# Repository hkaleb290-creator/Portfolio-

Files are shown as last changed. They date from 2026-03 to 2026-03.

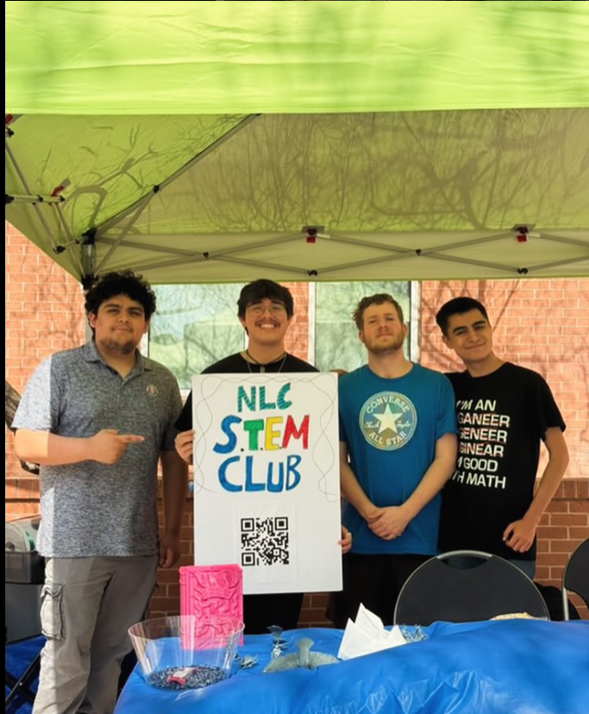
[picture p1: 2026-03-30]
1500.png

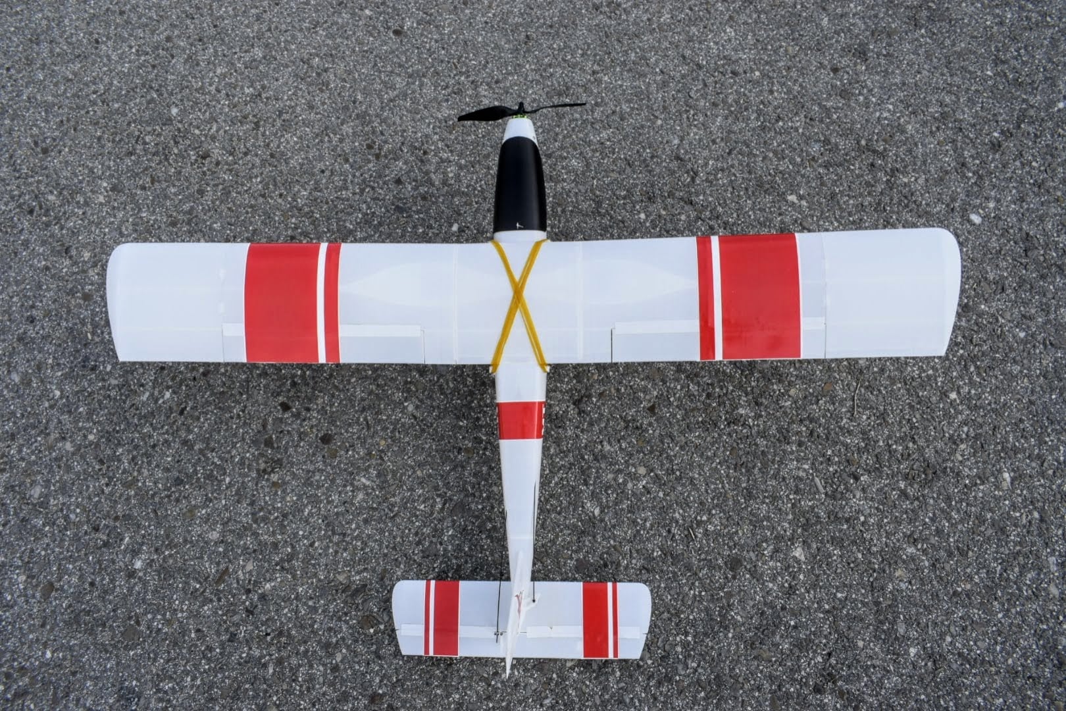
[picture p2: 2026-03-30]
images/_DSC0056.jpg

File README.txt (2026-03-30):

Free RC airplane by Eclipson on Thingiverse: https://www.thingiverse.com/thing:3302937

Summary:
-Free version of the 3D printed RC airplane Eclipson Model T. The free version available here does not include landing gear and floats. You will need to hand launch the airplane. Installing a folding propeller is recommended to avoid breaking it during landing.-More information about Eclipson: https://www.eclipson-airplanes.com/https://www.youtube.com/watch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

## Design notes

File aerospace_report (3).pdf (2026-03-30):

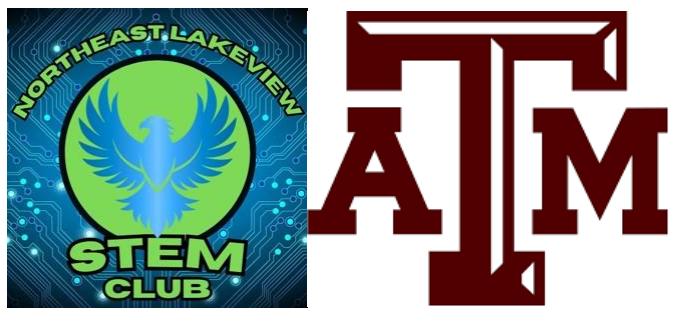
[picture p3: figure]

NLC STEM Club | Environmental Monitoring UAV | Page 1 of 23

### NLC STEM Club

Northeast Lakeview College (Alamo Colleges)

# Fixed-Wing UAV Design and Environmental Data Acquisition Using Additive Manufacturing

Lead Researchers
Aiden Ware Bosanko · Kaleb Harris · Jorge Cruz William Van Cleave · Isaiah Jimenez · Angelo Mejia

Faculty Advisors
Prof. Mitchell · Prof. Dan Ball · Prof. Sue Stankus · Prof. Rebecca Guevara

Northeast Lakeview College (Alamo Colleges) September 11, 2025 — March 2026

### Table of Contents

### 3. Results and Data Analysis | TBD

## Fixed-Wing UAV Design and Environmental Data Acquisition Using Additive Manufacturing

Author(s)/Researchers:
- Lead Researchers/Principal Investigators: Aiden Ware Bosanko (Mechanical), Kaleb Harris (Mechanical & Software), Jorge Cruz (Mechanical, Software & Research Lead), William Van Cleave (Mechanical), Isaiah Jimenez (Electrical), Angelo Mejia (Electrical)
- Researcher Contributors/Collaborators: Samuel Cedeno, Kyle McCracken, Alex (Electrical), Austin (Electrical), Tyler Rankins (Electrical)
- Support/Technical Contributors: Navora Medina (Historian), Talan (Software), Chris (Software)
- Faculty Advisors: Professor Mitchell, Professor Dan Ball, Professor Sue Stankus, Professor Rebecca Guevara

Institution: Northeast Lakeview College (Alamo Colleges)
Date: September 11, 2025

Abstract

Introduction: Air quality in the San Antonio region is a documented public health concern, yet spatially distributed, low-altitude atmospheric data remains scarce. The NLC STEM Club at Northeast Lakeview College set out to change that by designing, building, and flying a 3D-printed fixed-wing UAV capable of collecting real-time air quality and atmospheric data across the greater San Antonio area.
Methodology: We selected the open-source Eclipson Model T airframe and fabricated it using Lightweight PLA (LW-PLA) filament, reinforced with carbon fiber wing spars. A Matek F405-WMN flight controller running INAV firmware handles all autonomous and manual flight operations. We mounted a separate Arduino Nano microcontroller to manage the sensor payload — a BMP280 atmospheric pressure sensor and an MQ135 air quality sensor — logging all readings to a SanDisk 32GB microSD card every two seconds.
Results: Physical assembly of the integrated system began March 22, 2026, following 28 weeks of design, procurement, and fabrication work. Flight testing and sensor data collection are scheduled to follow. Results — including GPS-logged flight tracks, air quality readings, and pressure-altitude profiles — will be documented and added to this report upon completion.
Conclusion: We show that a college STEM club can design, build, and fly a capable research-grade UAV using accessible components and open-source tools for under $500. Our dual-subsystem architecture — separating flight avionics from the sensor payload — is practical, reproducible, and extensible for future environmental research programs.

### 1. Introduction

### 1.1. The Growing Role of UAVs in Environmental Science

UAVs have become one of the most powerful tools available for environmental monitoring. They can reach remote or hazardous locations, fly at low altitudes, and carry modular sensor payloads — all at a fraction of the cost of manned aircraft. Traditional ground-based monitoring stations do important work, but they're stuck in one place. UAVs break that limitation by enabling dynamic, geographically distributed sampling missions that teams can deploy and reconfigure quickly.

The urgency of this research is underscored by local conditions. According to the American Lung Association's 2025 State of the Air report, the San Antonio–New Braunfels–Kerrville metro area ranked 20th worst in the nation for ground-level ozone pollution, with Bexar County averaging 10.7 unhealthy ozone days per year — earning a failing grade. Contributing factors include vehicle emissions, proximity to the Eagle Ford Shale oil and gas development, industrial activity, and the region's valley geography, which traps pollutants during temperature inversions. Fixed-wing UAVs offer a uniquely powerful tool for studying these conditions, enabling spatially distributed, low-altitude sampling across the neighborhoods, corridors, and open areas that fixed ground stations cannot reach.

The NLC STEM Club built this UAV to collect real-time environmental data — air quality, atmospheric pressure, temperature, and humidity — over the San Antonio area. We deliberately chose a fixed-wing platform over a multirotor because fixed-wing aircraft are more aerodynamically efficient and cover more ground on the same battery. Using the Eclipson Model T as our base airframe and building a custom electronics and sensor stack on top of it, our goal was a capable, reproducible, well-documented research platform that other student teams could replicate.

### 1.2. From Quadcopter to Fixed-Wing: A Platform Evolution

We originally planned to build a quadcopter. After a series of team discussions and a hard look at our mission requirements, we switched to fixed-wing. Quadcopters are easy to build and can hover, but they burn through battery life fast just staying in the air. For a mission focused on covering ground and sampling air quality across a wide area, that's a serious limitation. Fixed-wing aircraft glide efficiently and stay airborne much longer on the same power. The switch meant more work for our Mechanical team, who had to redesign and reprint the entire airframe — but the performance gains are worth it.

### 1.3. Research Objectives and Scope

The primary objectives of this project are:

- To design, fabricate, and assemble a fully functional 3D-printed fixed-wing UAV using the Eclipson Model T airframe as the structural foundation.
- To integrate a complete electronics stack including a flight controller, GPS module, ESC, brushless motor, servos, and an RC link capable of autonomous and manual flight.
- To develop and deploy an onboard environmental sensor payload — including atmospheric pressure and air quality sensors — managed by an Arduino Nano microcontroller.
- To log all collected environmental data to onboard storage for post-flight analysis and reporting.
- To document the full design, build, integration, and testing process in a formal research report suitable for academic and portfolio use.

### 1.4. System Overview

At a high level, the UAV system operates as two independent but physically integrated subsystems. The first is the flight-critical avionics stack: a Matek F405-WMN flight controller running INAV firmware, fed by a BN-220 GPS module and commanded via a HappyModel ELRS receiver linked to a Jumper Smart ELRS ground transmitter. This stack controls all flight surfaces through four metal gear servos and drives the SunnySky X2212 1250KV brushless motor through a 40A ESC. Power for the entire avionics stack is drawn from an OVONIC 4S 2200mAh LiPo battery. The second subsystem is the research payload: an Arduino Nano V3.0 microcontroller that independently reads from a BMP280 atmospheric pressure sensor and an MQ135 air quality sensor every two seconds, time-stamps each reading, and writes the data to a SanDisk 32GB microSD card in CSV format. A manual SPST toggle switch allows the pilot to start and stop data logging during flight without interrupting vehicle operation. This dual-subsystem architecture ensures that sensor activity cannot interfere with flight-critical avionics, and that the research payload can be developed, tested, and modified independently of the flight system.

### 2. Design and Methodology

### 2.1. Airframe Selection and Fabrication

We chose the Eclipson Model T because it's open-source, fully 3D-printable, and designed for stable, efficient flight — exactly what a club-level research build needs. We print the airframe using Lightweight PLA (LW-PLA), a thermally foamed filament that is about 40-50% less dense than standard PLA. That weight reduction makes a real difference for flight time without making the parts harder to print. We reinforce the wings with 2mm carbon fiber rods as spars, which keep the wing geometry rigid under aerodynamic loads without adding significant weight.

Our Mechanical team handles all printing, post-processing, and structural assembly. We carefully tune print parameters to get the right balance of weight and strength, and we inspect every part for layer adhesion and dimensional accuracy before it goes into the build. We bond key structural joints with epoxy and cyanoacrylate — the same approach used across professional and hobbyist RC aircraft builds.

### 2.2. Propulsion and Control Surface Systems

We drive the aircraft with a SunnySky X2212 1250KV brushless motor — a reliable, well-regarded choice that matches our expected all-up weight. A Gemfan nylon propeller pairs with the motor, and a 40A brushless ESC rated for 2-4S LiPo handles the power conversion. We run everything off an OVONIC 4S 2200mAh 14.8V LiPo battery, which gives us the energy density we need to hit our target flight time.

We use four RGBZONE ES08MA II metal gear servos to actuate the ailerons, elevator, and rudder. We went with metal gears specifically because they hold their neutral position more consistently than plastic gears — something that matters a lot for stable fixed-wing flight. Each servo connects to the flight controller through standard extension cables.

### 2.3. Flight Controller and Navigation

Our flight controller is the Matek F405-WMN running INAV firmware. We picked this combination because INAV has excellent native fixed-wing support, a clean configurator interface, and autonomous flight features that are genuinely accessible without a steep learning curve — important for a club where not everyone has flight controller experience coming in. The F405-WMN brings onboard OSD and blackbox logging on top of that. Together they give us fully manual control, GPS-stabilized flight, waypoint navigation, loiter, and return-to-home — everything we need to run a structured environmental sampling mission.

A BN-220 dual GPS module feeds position and navigation data to INAV over TTL serial, enabling position hold, heading stabilization, and autonomous waypoint missions. On the radio side, we use a Jumper Smart ELRS 2.4GHz transmitter on the ground paired with a HappyModel ELRS nano receiver onboard. ELRS gives us a low-latency, long-range control link with live telemetry feedback — well beyond what we need for our planned missions.

### 2.4. Environmental Sensor Payload and Data Acquisition

We manage the entire research payload with an Arduino Nano V3.0 that runs completely independently from the flight controller. We deliberately separated these two systems so that sensor activity can never affect flight stability — if something goes wrong with the data logging, the plane keeps flying. The payload itself includes a BMP280 for barometric pressure and altitude, and an MQ135 for air quality monitoring, including volatile organic compounds (VOCs) and CO₂-equivalent readings.

Every sensor reading gets time-stamped and written to a SanDisk 32GB microSD card through an onboard card reader module. We added a manual SPST toggle switch to the payload circuit so the pilot or ground crew can start and stop logging mid-flight without touching the avionics. That lets us target specific flight phases for data collection — like activating logging only when we enter a loiter pattern over a point of interest — which keeps the data clean and the post-flight analysis manageable.

Table 1: Onboard Sensor Specifications

Specification | BMP280 | MQ135 | Notes
Measures | Pressure, temperature, altitude | VOC, CO₂-equivalent, air quality | Primary environmental parameters
Interface | I2C (address 0x76) | Analog (A1 on Arduino Nano) | BMP280 via Wire library; MQ135 via analogRead()
Supply Voltage | 3.3V | 5V | Different voltages — wiring must be separated
Pressure Range | 300–1100 hPa | N/A | Covers sea level to ~9,000m altitude
Temperature Range | −40°C to +85°C | −10°C to +50°C (operating) | BMP280 has wider operating range
Pressure Accuracy | ±1 hPa (typical) | N/A (relative output) | BMP280 factory calibrated
Output Format | Compensated float values | 10-bit ADC raw (0– 1023) | MQ135 converted to percentage in firmware
Altitude Resolution | ~0.16m (high resolution mode) | N/A | Computed from pressure using barometric formula
Warm-up Time | ~2ms (fast startup) | 24–48 hours for baseline stability | MQ135 requires extended burn-in for accuracy
Data Rate | Up to 157 Hz (normal mode) | Limited by Arduino analog read speed | Logged at 0.5 Hz (every 2 seconds) in firmware

### 2.5. Team Structure and Division of Responsibilities

We organized the project into four interdisciplinary teams, each led by a club officer, all working in parallel throughout the build:

- Mechanical & Structural Team (Aiden Ware Bosanko, Kaleb Harris, Jorge Cruz): Responsible for all 3D printing, airframe assembly, structural reinforcement, and physical integration of components into the fuselage and wing structures.
- Electronics & Power Team (Isaiah Jimenez, Angelo Mejia, Alex, Austin, Tyler Rankins): Responsible for all wiring, soldering, ESC configuration, power distribution, and electrical system validation.
- Software & Data Team (Kaleb Harris, Jorge Cruz, Talan, Chris): Responsible for flight controller configuration via the INAV Configurator, Arduino sensor code development, data logging pipeline, and post-flight data analysis.
- Documentation & Reporting Team: Responsible for maintaining build logs, capturing photos and video throughout the process, and compiling this final research report.

### 2.6. Predicted Flight Parameters

Based on the Eclipson Model T specifications and the selected component stack, the following flight parameters have been estimated prior to first flight. These values will be verified and updated following flight testing.

Parameter | Predicted Value | Notes
Airframe | Eclipson Model T | Open-source 3D-printable fixed-wing
Wingspan | ~1,200 mm (47 in) | Per Eclipson Model T design specs
Est. All-Up Weight | ~800–1,100 g (1.8–2.4 lbs) | Battery, electronics, and payload included
Cruise Speed | ~45–65 km/h (28–40 mph) | Based on motor/prop selection
Stall Speed | ~28–35 km/h (17–22 mph) | Conservative estimate for safe hand-launch
Expected Flight Time | ~20–35 minutes | 4S 2200mAh at cruise throttle
Flight Modes | Manual, Stabilize, GPS Hold, Waypoint | Via INAV on Matek F405-WMN
Data Collection Altitude | ~30–100 m AGL | Target operational altitude range
Launch Method | Hand launch | Belly landing on grass — no landing gear

### 2.7. Lessons Learned During Development

Building this UAV over 28 weeks taught us a lot — some lessons came easy, others cost us time. The biggest was the mid-project switch from quadcopter to fixed-wing. Our core mission never changed, but the platform change meant our Mechanical team had to scrap weeks of design work and start over. Looking back, if we had done a more thorough mission analysis at the very beginning, we would have landed on fixed-wing from day one.

Parts sourcing was another hard lesson. We ended up swapping out four components mid-build — the motor, propeller, sensor package, and filament — because of availability, compatibility, or cost issues that we didn't catch early enough. Next time, we'd identify backup options for every critical component during the planning phase rather than scrambling for replacements mid-build.

INAV surprised us with how much there was to learn. Members who hadn't worked with flight controllers before found the configuration process more involved than expected. We'd strongly recommend that future teams spend dedicated time just getting comfortable with the firmware on a bench setup — before any wiring goes into the airframe.

The one decision we'd make again without hesitation: keeping the Arduino sensor payload completely separate from the flight controller. It let our Software and Electronics teams work in parallel without stepping on each other, and any sensor problem we hit could be debugged in isolation without ever touching the flight system. Clean separation of concerns makes everything easier.

### 4. Discussion

### 4.1. Sources of Error and Uncertainty

While full discussion of results is pending flight testing, several known sources of error and uncertainty have been identified during the design and build phases. These are documented here to provide context for interpreting future flight data.

Sensor Calibration: The MQ135 gas sensor requires a warm-up period of approximately 24–48 hours in clean air for accurate baseline calibration. Readings taken during early flights may exhibit elevated baseline drift until the sensor stabilizes. The BMP280 pressure sensor is factory-calibrated but may require an altitude offset correction based on local atmospheric conditions at the time of flight.

GPS Accuracy: The BN-220 GPS module has a stated horizontal position accuracy of approximately 2.5m CEP under open-sky conditions. Flights near buildings, trees, or other obstructions may experience degraded GPS accuracy, affecting the precision of geotagged sensor data.

Airspeed Variation: Without a dedicated airspeed sensor, the UAV relies on GPS ground speed for navigation. Wind conditions will introduce variation between ground speed and true airspeed, potentially affecting motor throttle levels and sensor exposure time at any given location.

Sensor Placement and Thermal Interference: Placement of the BMP280 and MQ135 sensors within or near the fuselage may expose them to heat generated by the ESC, motor, and flight controller. This thermal interference could introduce positive bias in temperature and air quality readings. Proper shielding and placement away from heat sources will be critical.

Manual Data Logging Trigger: The use of a manual SPST toggle switch to initiate and terminate data logging introduces operator-dependent variability. There may be inconsistencies in exactly when logging begins and ends relative to specific flight phases. A future improvement would be to trigger logging automatically based on flight mode or GPS altitude.

LW-PLA Structural Variability: Lightweight PLA exhibits variable expansion characteristics during printing. Differences in print temperature, ambient humidity, and layer adhesion across multiple print sessions may result in slight dimensional inconsistencies between airframe components, potentially affecting aerodynamic symmetry.

### 4.2. Interpretation of Results

[To be completed following flight testing. Will include analysis of sensor data, flight performance, and comparison against predicted parameters.]

### 5. Advanced Applications and Future Work

### 5.1. Towards Longer Endurance and Solar-Assisted Flight

We originally planned to include solar panels — thin-film cells mounted on the wing surfaces, with a boost/buck converter feeding charge back into the flight battery. We descoped that for the initial build to keep complexity and cost manageable, but we haven't abandoned it. The Eclipson Model T's broad, flat wing surfaces are actually ideal for solar integration. Even a modest supplemental charge during cruise could meaningfully extend mission time, especially on a clear Texas day.

A natural next step would be to bring solar back in — starting with ground-based characterization tests to measure realistic charge rates under San Antonio sunlight before committing to full integration.

### 5.2. Expanded Sensor Suite and Real-Time Telemetry

Right now our payload focuses on pressure and air quality. That's a solid start, but there's a lot of room to grow. A BME280 would add temperature and humidity to the mix. PM2.5/PM10 particulate sensors would open the door to real air pollution studies. A UV index sensor could map solar radiation across the city. The Arduino Nano has plenty of I2C and analog headroom to run several of these at the same time.

We're also excited about real-time telemetry. Right now everything gets analyzed after the flight, but there's no reason we couldn't stream sensor data live to the ground station via the ELRS link or a dedicated telemetry radio. Imagine watching air quality readings update on a map in real time as the plane flies overhead — and choosing to loiter over a pollution hotspot on the spot rather than discovering it in post-processing.

### 5.3. Autonomous Mission Planning and AI-Driven Analysis

INAV supports full waypoint missions, which means we can pre-program a grid pattern at a fixed altitude and let the aircraft execute it autonomously. That opens up systematic, repeatable sampling — fly the same grid at dawn and at noon, and you've got a direct comparison of morning versus midday air quality across the same geography. No pilot input required once the mission starts.

Further down the road, the time-stamped CSV files we log are a natural fit for machine learning. Train an algorithm on enough flight data and it could identify spatial air quality patterns, correlate readings with altitude or wind speed, or flag anomalies worth investigating. That's exactly what professional environmental UAV programs are doing right now — and it's a realistic next step for this project.

### 5.4. Platform Replication and Open-Source Documentation

One outcome we're genuinely proud of is how replicable this build is. The Eclipson Model T is open-source. Every component we chose is available on Amazon. The total budget is under $500. Another student team — anywhere — could reproduce this platform from our parts list alone. We plan to open-source our Arduino code, our INAV configuration files, and our full build documentation so other clubs don't have to start from scratch the way we did.

### 6. Conclusion

We set out to prove that a college STEM club could build a real research-grade UAV — not from a kit, not with a faculty member doing the hard parts, but through genuine engineering work spanning mechanical fabrication, electronics integration, firmware configuration, and software development. This report documents what that actually looks like: 28 weeks, one major platform pivot, four teams, and a lot of problem-solving.

Switching from quadcopter to fixed-wing was the hardest call we made. It set our Mechanical team back and forced everyone to learn new skills fast. But it was the right call. A well-configured fixed-wing UAV covers more ground, stays airborne longer, and is simply a better tool for wide-area environmental monitoring. We'd make that call again.

What we built here — a flight-critical avionics stack running INAV, completely separated from an independent Arduino sensor payload — is modular, extensible, and designed to be built upon. This isn't a finished product. It's a foundation. The future work section lays out a real roadmap: solar endurance, live telemetry, autonomous grid missions, and eventually machine learning analysis of the data we collect.

[Final flight results and data analysis to be added following flight testing.]

What this project ultimately proves is simple: the gap between a student club and a serious aerospace research program is a lot smaller than it looks. The tools exist. The knowledge is accessible. The drive is here. We just have to show up and build it.

Acknowledgements

This project would not have been possible without the support and guidance of our faculty advisors: Professor Mitchell, Professor Dan Ball, Professor Sue Stankus, and Professor Rebecca Guevara. Their encouragement, technical input, and willingness to give us the space to learn by doing this project shaped at every stage.

We also want to recognize Navora Medina, whose work as our project historian kept the team organized and on track across 28 weeks a job that is easy to overlook and impossible to replace. And every club member who showed up, asked questions, soldered a wire, or printed a part: this is your project too.

We owe special acknowledgement to the founding members of the NLC STEM Club. Two years ago, Kaleb Harris, Jorge Cruz, Aiden Ware Bosanko, Sam Cedeno, and Thomas Goosetree built this club from nothing. Aiden served as Vice President, Sam as our Technical Lead, and Thomas as a co-founder and together they set the vision, the culture, and the standard that made a project like this possible. Everything we've accomplished here started with them.

Finally, we acknowledge the broader open-source communities behind the Eclipson Model T airframe, the INAV flight controller firmware, and the Arduino ecosystem. This project stands on the shoulders of thousands of engineers and hobbyists who shared their work freely. We intend to do the same.

References

[1] Eclipson. (2023). Model T — 3D Printed RC Airplane. Retrieved from https://www.eclipson-airplanes.com/model-t
[2] INAV Project. (2024). INAV — Navigation-enabled flight controller firmware. GitHub. Retrieved from https://github.com/iNavFlight/inav
[3] Matek Systems. (2023). F405-WMN Flight Controller Manual. Retrieved from http://www.mateksys.com/?portfolio=f405-wmn
[4] Arduino. (2024). Arduino Nano — Product Page and Technical Documentation. Retrieved from https://www.arduino.cc/en/pmwiki.php?n=Main/ArduinoBoardNano
[5] Adafruit Industries. (2024). Adafruit BME280 Library for Arduino. GitHub. Retrieved from https://github.com/adafruit/Adafruit_BME280_Library
[6] American Lung Association. (2025). State of the Air 2025 Report: San Antonio–New Braunfels– Kerrville, TX Metro Area. Retrieved from https://www.lung.org/research/sota
[7] SunnySky. (2023). X2212 Series Brushless Motor Specifications. Retrieved from https://www.sunnyskyusa.com
[8] HappyModel. (2024). EP1/EP2 ExpressLRS Nano Receiver Documentation. Retrieved from https://www.happymodel.cn
[9] Bosch Sensortec. (2023). BMP280 Digital Pressure Sensor — Datasheet. Retrieved from https://www.bosch-sensortec.com/products/environmental-sensors/pressure-sensors/bmp280/
[10] Zhengzhou Winsen Electronics. (2023). MQ-135 Sensitive Material Datasheet. Retrieved from https://www.winsen-sensor.com/sensors/air-quality-sensor/mq135.html

Appendix A: Parts & Budget

The following table lists all components purchased for the project, including substitutions made during the build phase. Items marked with an asterisk (*) replaced original components from the initial parts list.

Category | Component | Description | Price
Airframe | Filament * | OVERTURE Lightweight PLA — replaced eSUN LW PLA | $45
Airframe | Reinforcement | 2mm Carbon Fiber Wing Spars (10pcs) | $12
Flight Systems | Flight Controller | Matek F405-WMN STM32F405 OSD Blackbox / INAV | $65
Flight Systems | GPS Module | BN-220 Dual GPS TTL | $23
Flight Systems | Motor * | SunnySky X2212 1250KV — replaced FLASH HOBBY D2830 | $20
Flight Systems | ESC | 40A Brushless ESC 2-4S 5V 3A BEC | $13
Flight Systems | Propeller * | Gemfan Nylon Propeller — replaced folding 1060/1160 | $12
Flight Systems | Servos | RGBZONE ES08MA II Metal Gear Servos (4pcs) | $24
Flight Systems | Transmitter | Jumper Smart ELRS 2.4GHz RC Transmitter | $65
Flight Systems | Receiver | HappyModel ELRS EP Nano Long Range Receiver | $24
Research & Power | Microcontroller | Arduino Nano V3.0 ATmega328P | $8
Research & Power | Sensor Package * | BMP280 Atmospheric + MQ135 Air Quality | $18
Research & Power | Data Storage | SanDisk 32GB MicroSD & Card Reader Module | $21
Research & Power | Flight Battery | OVONIC 4S LiPo 2200mAh 14.8V 130C | $45
Research & Power | Charger | B6 Balance Charger 80W Mini LiPo | $30
Tools | Soldering Station | 80W Electric Soldering Iron Adjustable Temp | $24
Tools | Wiring/Misc | Wire, XT60, Epoxy, Foam Cure, Insta-Set, Component Kit | $107
Tools | Toggle Switch | SPST Mini Toggle Switch 2 Pin (10pcs) | $8
TOTAL — All Purchased Components | | | $465

* Denotes component replaced from original parts list.

Appendix B: Project Timeline

This project ran for approximately 28 weeks, beginning September 11, 2025 and targeting a first flight in March 2026. The timeline below reflects the actual phased progression of work across all four teams.

Weeks | Dates | Phase | Key Activities
1–4 | Sep 11 – Oct 9, 2025 | Design & Planning | Platform selection, parts research, team formation, quadcopter-to-fixed-wing transition, parts list finalized
5–8 | Oct 10 – Nov 6, 2025 | Procurement & Setup | Parts ordered, 3D printer calibration, filament testing, INAV research, Arduino sensor library testing
9–14 | Nov 7 – Dec 18, 2025 | Fabrication Phase 1 | Eclipson Model T airframe printing begins, carbon fiber spar integration, fuselage assembly
15–18 | Dec 19, 2025 – Jan 15, 2026 | Winter Break / Build | Continued printing, wing assembly, component fitting, parts substitutions finalized
19–22 | Jan 16 – Feb 12, 2026 | Electronics Integration | ESC wiring, FC mounting, servo installation, ELRS binding, GPS wiring
23–25 | Feb 13 – Mar 5, 2026 | Software & Sensor Config | INAV configuration, Arduino sensor code, SD logging validation, bench testing
26–27 | Mar 6 – Mar 19, 2026 | Pre-Assembly & Final Check | Component verification, control surface linkage prep, center of gravity planning, pre-assembly inspection
28 | Mar 22, 2026 | Physical Assembly Begins | First day of full physical assembly — all procured components brought together for integration

Appendix B2: Team Roles & Responsibilities

The following table details each team member's role and primary responsibilities within the project.

Name | Role | Team | Primary Responsibilities
Aiden Ware Bosanko | Lead Researcher | Mechanical | Airframe design, 3D printing, structural assembly
William Van Cleave | Lead Researcher | Mechanical | Mechanical team lead, airframe assembly and structural integration
Kaleb Harris | Lead Researcher | Mechanical & Software | Airframe assembly, INAV configuration, data pipeline
Jorge Cruz | Lead Researcher | Mechanical, Software & Research Lead | Airframe assembly, INAV setup, software integration, and lead of research direction
Isaiah Jimenez | Lead Researcher | Electrical | Wiring, soldering, ESC & power system setup
Angelo Mejia | Lead Researcher | Electrical | Wiring, component integration, electrical validation
Samuel Cedeno | Research Contributor | Research | Research contributions and project support
Kyle McCracken | Research Contributor | Research | Ideation, conceptual input, and project support
Alex | Research Contributor | Electrical | Electrical assembly and wiring support
Austin | Research Contributor | Electrical | Electrical assembly and wiring support
Tyler Rankins | Research Contributor | Electrical | Electrical assembly and wiring support
Navora Medina | Support Contributor | Historian | Project historian — documentation, timeline tracking, and keeping the team on schedule
Talan | Support Contributor | Software | Arduino code development and sensor testing
Chris | Support Contributor | Software | Arduino code development and data logging

Appendix C: System Wiring Diagram

The diagram below illustrates the complete wiring and signal architecture of the UAV. The system is divided into two independent subsystems: the flight-critical avionics stack (powered directly from the LiPo battery via the ESC's BEC) and the research payload (managed by the Arduino Nano). This separation ensures that sensor activity cannot affect flight controller performance.

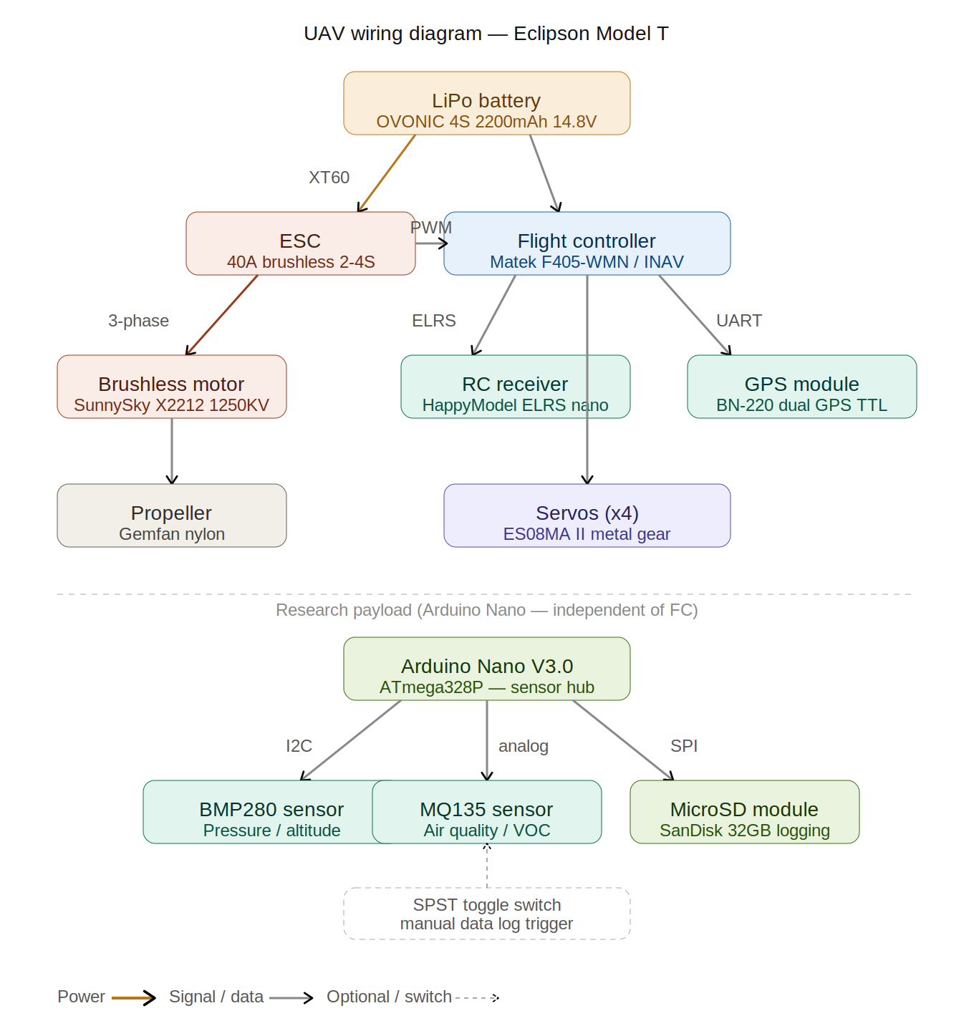
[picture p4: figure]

Figure C1: UAV system wiring diagram showing power flow (amber), signal/data connections (gray), and optional switch connections (dashed). The dashed line separates the flight systems (above) from the research payload (below).

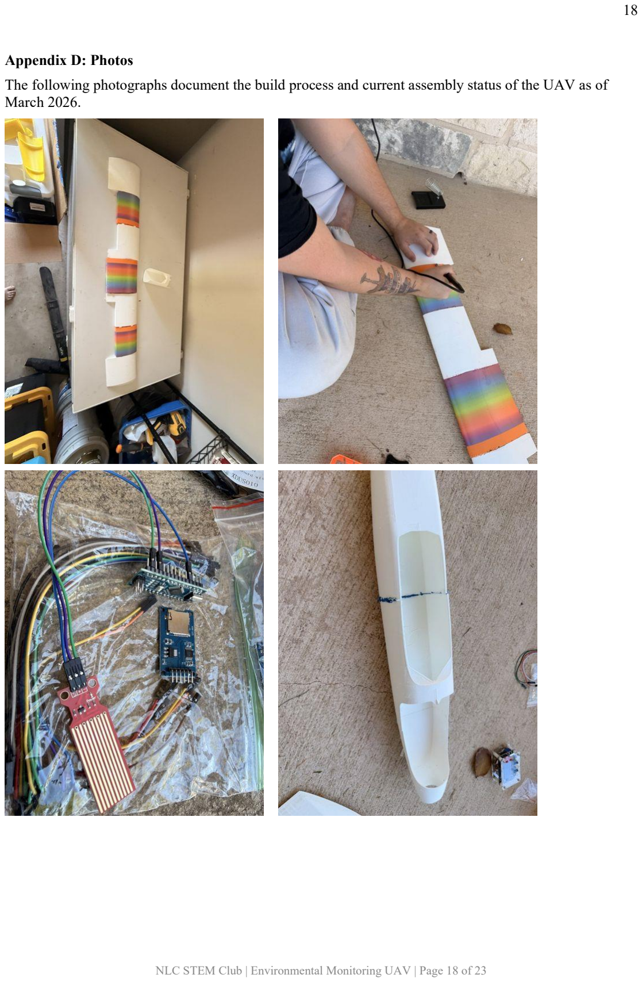
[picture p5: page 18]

Appendix D: Photos

The following photographs document the build process and current assembly status of the UAV as of March 2026.

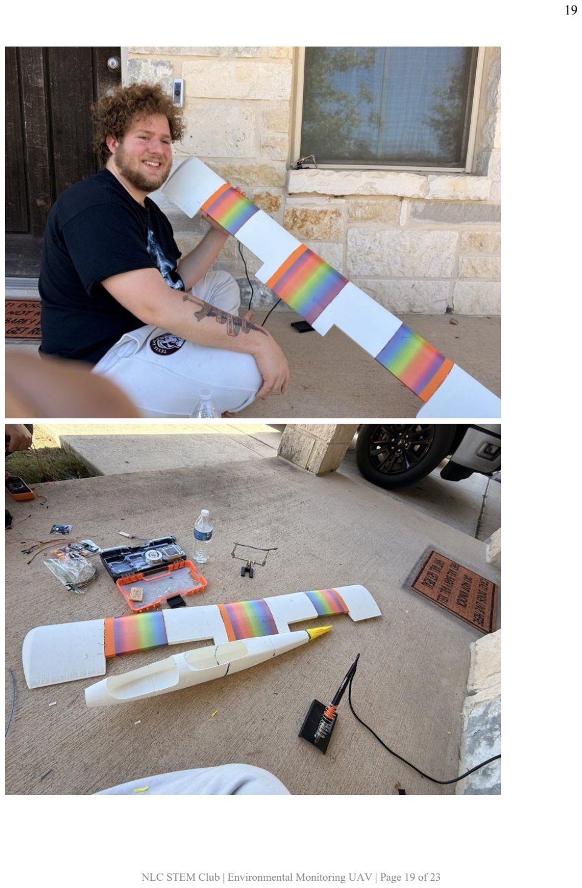
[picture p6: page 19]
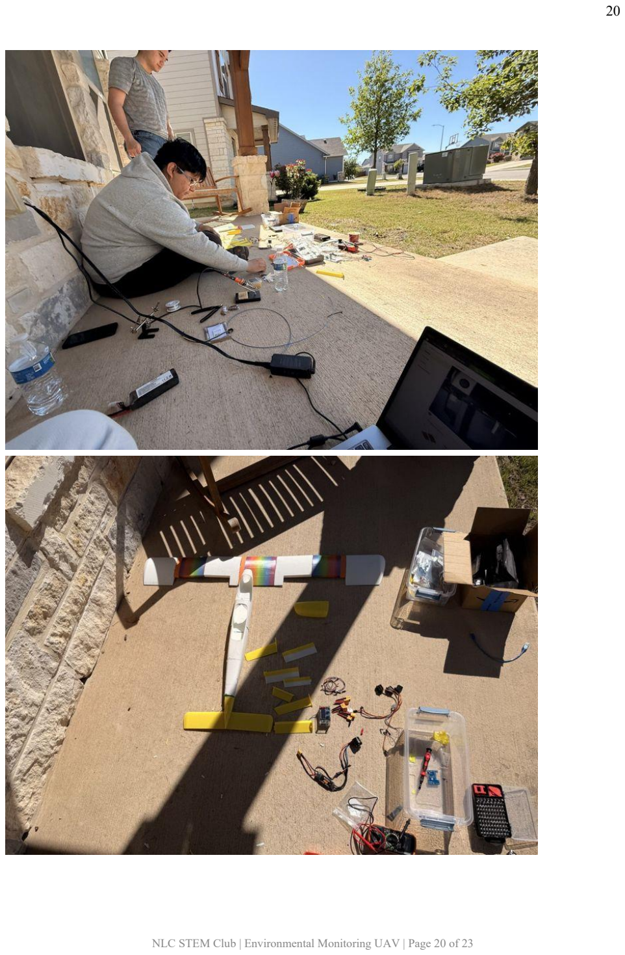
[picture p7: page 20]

Appendix E: Arduino Sensor Logger Code

The following is the intended Arduino Nano sensor logging code for the UAV's research payload. This code reads data from the BME280 atmospheric sensor and MQ135 air quality sensor, then logs all readings to a CSV file on the onboard microSD card at a fixed 2-second interval. Note: this code has not yet been fully validated in the integrated hardware environment and may require adjustments following bench testing.

Libraries Required:
- Adafruit BME280 Library
- Adafruit Unified Sensor Library
- SD (built-in Arduino library)
- SPI (built-in Arduino library)
- Wire (built-in Arduino library)

Pin Assignments:
- MQ135 Air Quality Sensor: Analog pin A1
- BME280 Atmospheric Sensor: I2C — SDA to A4, SCL to A5, address 0x76
- MicroSD Card Module: SPI — CS to D10, MOSI to D11, MISO to D12, SCK to D13

CSV Output Format:
Each row logged to data.csv contains: timestamp_ms, mq135_raw, mq135_percent, bme_temp_c, bme_humidity_percent, bme_pressure_hpa, bme_altitude_m

Source Code (nano_sensor_logger.ino):

#include <SPI.h>

#include <SD.h>

#include <math.h>

#include <Wire.h>

#include <Adafruit_Sensor.h> #include <Adafruit_BME280.h>

// Pin assignments (Arduino Nano)
const uint8_t PIN_MQ135 | = A1;
const uint8_t PIN_SD_CS | = 10;
const uint8_t BME280_I2C_ADDRESS = 0x76;
const char *LOG_FILE | = "data.csv";
const unsigned long LOG_INTERVAL_MS = 2000;

unsigned long lastLogMs = 0;
bool sdReady = false;
bool bmeReady = false;
Adafruit_BME280 bme;

struct SensorData {
unsigned long timestampMs; int mq135Raw;
float mq135Percent;
float bmeTempC;
float bmeHumidity;
float bmePressurehPa;
float bmeAltitudeM;
};

int readAveragedAnalog(uint8_t pin, uint8_t samples = 10) {

long total = 0;
for (uint8_t i = 0; i < samples; i++) { total += analogRead(pin);
delay(3);
}
return (int)(total / samples); }

SensorData readSensors() {
SensorData d;
d.timestampMs | = millis();
d.mq135Raw | = readAveragedAnalog(PIN_MQ135);
d.mq135Percent | = (d.mq135Raw / 1023.0) * 100.0;
if (bmeReady) {
d.bmeTempC | = bme.readTemperature();
d.bmeHumidity | = bme.readHumidity();
d.bmePressurehPa = bme.readPressure() / 100.0;
d.bmeAltitudeM = bme.readAltitude(1013.25);
} else {
d.bmeTempC = d.bmeHumidity = d.bmePressurehPa = d.bmeAltitudeM = NAN; }
return d;
}

bool appendCsvRow(const SensorData &d) {
if (!sdReady) return false;
File file = SD.open(LOG_FILE, FILE_WRITE); if (!file) return false;
file.print(d.timestampMs); | file.print(',');
file.print(d.mq135Raw); | file.print(',');
file.print(d.mq135Percent, 1); file.print(','); if (isnan(d.bmeTempC)) {
file.print(F("nan,nan,nan,nan"));
} else {
file.print(d.bmeTempC, 2); | file.print(',');
file.print(d.bmeHumidity, 2); | file.print(',');
file.print(d.bmePressurehPa, 2); file.print(','); file.print(d.bmeAltitudeM, 2);
}
file.println();
file.close();
return true;
}

void setup() {
Serial.begin(9600);
Wire.begin();
bmeReady = bme.begin(BME280_I2C_ADDRESS); sdReady = SD.begin(PIN_SD_CS);
if (sdReady) {
File f = SD.open(LOG_FILE, FILE_WRITE);
if (f && f.size() == 0)

f.println(F("timestamp_ms,mq135_raw,mq135_pct,bme_temp_c,bme_hum_pct,bme_pres_hpa, bme_alt_m"));
if (f) f.close();
}
}

void loop() {
unsigned long now = millis();
if (now - lastLogMs >= LOG_INTERVAL_MS) {

lastLogMs = now;
SensorData data = readSensors(); appendCsvRow(data);
}
}

Note: Full source file including serial debug output and water sensor support is available in the project repository. This appendix shows the core logging logic.

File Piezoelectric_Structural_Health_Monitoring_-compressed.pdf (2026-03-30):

### A Comparative Study on the Efficacy of Piezoelectric Transducers for Structural Health Monitoring on Anisotropic and Isotropic Material Testbeds

Author(s)/Researchers:

- Lead Researchers/Principal Investigators: Aiden Ware Bosanko, Sam Cedeno
- Researcher Contributors/Collaborators: Isaiah Jimenez, Mary Naut, Madelyn Pickett, Kaleb Harris, Paola Contreras
- Support/Technical Contributors: Ace Laurent, Thomas Goosetree, Devin Arnberg, David Graves, Jacob Jay, Anmol Ali, Ryan Sarmiento

Institution: Northeast Lakeview College (Alamo Colleges)

Date: October 19, 2025

### Abstract

Introduction: The imperative for robust and real-time Structural Health Monitoring (SHM) systems is growing in response to aging global infrastructure and the increasing use of novel materials in construction. This research provides a comparative analysis of the efficacy of commercial piezoelectric transducers for SHM applications on two distinct structural paradigms: a traditional anisotropic material (Cedar wood) and a modern isotropic material created via additive manufacturing (3D-printed PLA).

Methodology: Two model bridges—one constructed from Cedar wood (Bridge 1), the other 3D-printed from Polylactic Acid (Bridge 2)—were instrumented with four identical piezoelectric sensors. A novel, web-based Data Acquisition (DAQ) system was developed, enabling remote test initiation via a mobile interface and real-time data visualization. This system, orchestrated by an Arduino microcontroller, logged high-frequency sensor voltage data directly to a clean CSV format. The instrumented structures were subjected to a battery of tests: low-amplitude dynamic vibration, incremental static load application, and a terminal load-to-failure test on the Cedar bridge.

Results: The piezoelectric sensors demonstrated high fidelity in detecting dynamic events across both material types. The 3D-printed bridge (isotropic) exhibited sharper, higher-amplitude voltage spikes (peak vibration response: ~850 mV), characteristic of its higher stiffness and lower damping coefficient. The Cedar bridge (anisotropic) showed more attenuated, broader responses (peak vibration response: ~400 mV). Critically, during the load-to-failure test, the system registered a clear, fifteen-second pre-failure cascade of acoustic emissions, with voltage spikes increasing from a baseline of <10 mV to over 750 mV before the final fracture event, which saturated the 5V sensor limit.

Conclusion: This study validates the use of piezoelectric transducers as a highly effective method for event-based SHM. The comparative analysis reveals that the underlying material properties of a structure fundamentally influence the sensor output, a critical consideration for developing calibrated and intelligent monitoring systems. The successful detection of pre-failure stress waves provides strong evidence for the technology's application in predictive failure analysis. The development of a web-based control and visualization platform represents a significant step towards accessible, user-friendly SHM systems. This research serves as a foundational framework for developing sophisticated "digital twin" models and AI-driven prognostic health management (PHM) systems.

### 1. Introduction

### 1.1. The Modern Imperative for Structural Health Monitoring (SHM)

The lifecycle management of civil and mechanical infrastructure is a cornerstone of modern engineering. As bridges, buildings, and aircraft age, they are subject to material fatigue, environmental degradation, and accumulating damage from operational loads. SHM is the field dedicated to automating the process of damage detection and characterization. By embedding a network of sensors within a structure, engineers can monitor its health in real-time, moving from a reactive, schedule-based maintenance paradigm to a proactive, condition-based one. This research aims to contribute to this field by investigating a simple, yet powerful, sensing modality integrated with a modern data management framework.

### 1.2. Piezoelectric Transducers as a Sensing Modality

At the heart of any SHM system is the sensor. While fiber optics and strain gauges are common, piezoelectric transducers offer a unique combination of high sensitivity, wide bandwidth, and low cost. The piezoelectric effect is the internal generation of an electric charge in a material as a response to applied mechanical stress. This property makes them exceptionally well-suited for detecting dynamic events such as impacts, vibrations, and the high-frequency acoustic emissions (AE) generated by crack propagation. This study utilizes new, off-the-shelf piezoelectric sensors to ensure data consistency, allowing for a more direct comparison between the two bridge materials.

### 1.3. Research Objectives and Scope

The primary objectives of this thesis are:

- To design and validate a low-cost, high-fidelity SHM data acquisition (DAQ) system featuring a web-based user interface for remote control and real-time visualization.
- To analyze and quantify the response of piezoelectric sensors to dynamic, static, and failure-inducing loads.
- To conduct a comparative study of sensor performance on an anisotropic, natural material (Cedar wood) versus an isotropic, additively manufactured material (PLA).
- To establish a framework for how this fundamental data can inform the development of advanced, intelligent health management systems.

### 2. Experimental Design and Methodology

### 2.1. Testbed Construction: Material Paradigms

- Bridge 1 (Anisotropic): A simple beam bridge constructed from Cedar wood, chosen for its distinct grain, natural damping characteristics, and common use as a building material.

- Bridge 2 (Isotropic): A geometrically similar arched bridge model fabricated using a Fused Deposition Modeling (FDM) 3D printer with Polylactic Acid (PLA) filament. This represents a modern, rigid material with uniform properties.

### 2.2. Instrumentation and Data Acquisition (DAQ) System

A novel DAQ system was developed to provide a user-friendly and powerful interface for conducting the experiments.

- Sensing Elements: Four 27mm piezoelectric transducers.
- Microcontroller Core: An Arduino Uno, utilizing its 10-bit analog-to-digital converter (ADC) to read sensor voltages.
- Web-Based User Interface: A key innovation of this project was the development of a web application. This platform provided:
- Remote Control: The ability to initiate and stop data recording remotely from a mobile device or computer, ensuring consistency and reducing operator interference.
- Real-Time Visualization: Live graphing of incoming voltage data from all four sensors, allowing for immediate feedback during testing.
- Data Management: A clean, automated process for logging time-stamped voltage readings directly into a structured CSV file, eliminating manual data entry errors.

### 2.3. Sensor Placement and System Statics

Sensors were affixed using cyanoacrylate adhesive at locations of predicted high stress, informed by basic structural mechanics.

- Sensors 1 & 2: Placed towards the mid-span on the main load-bearing beams to measure maximum bending moments.
- Sensors 3 & 4: Placed near the bridge supports/abutments to measure shear stresses.

### 2.4. Testing Protocols

- Vibration Test: The bridge decks were tapped lightly with a consistent tool to induce free vibration.
- Weight Test: Calibrated weights were carefully placed on and removed from the center of the bridges.
- Break Test: The Cedar bridge (Bridge 1) was subjected to a steadily increasing load until catastrophic structural failure.

### 3. Results and Data Analysis

### 3.1. Data Identification and Pre-processing

The raw 10-bit ADC output (0-1023) was converted to millivolts (mV) using the formula: $Voltage (mV) = (ADC\_value / 1023) \times 5000$. Analysis of signal characteristics allowed for definitive identification of each dataset.

### 3.2. Test 1: Dynamic Vibration Response

The impulse response from tapping clearly shows the different damping characteristics of the materials.

Table 1: Peak Impulse Response to Vibration Event

Testbed | Material | Avg. Peak Voltage (mV) | Notes
Bridge 1 | Cedar (Anisotropic) | 385.1 | Rapid signal decay, high damping.
Bridge 2 | PLA (Isotropic) | 830.9 | Slower signal decay, low damping.

The PLA bridge, being stiffer and less damped, transmitted the vibration energy more efficiently to the sensors, resulting in a 116% higher average peak voltage.

### 3.3. Test 2: Static Load Application Response

The sensors correctly generated voltage spikes only upon the change in applied load.

### 3.4. Test 3: Destructive Load-to-Failure Analysis (Bridge 1 - Cedar)

This test provided the most compelling data for the system's utility in predictive failure analysis. The voltage-time series data shows a clear progression towards failure.

Table 2: Phased Analysis of Load-to-Failure Test on Bridge 1

Phase | Time Window (s) | Max Voltage (mV) | Signal Characteristics | Interpretation
1. Elastic Loading | 0 - 80 | 146.6 | Low-amplitude, sporadic spikes. | Wood fibers straining under load.
2. Pre-Failure Cascade | 80 - 95 | 752.7 | Rapid, high-amplitude, high-frequency spikes. | Micro-fractures forming and propagating.
3. Catastrophic Failure | ~95.5 | >5000 | Signal saturates the ADC limit. | Complete structural fracture.

The critical finding is the 15-second "Pre-Failure Cascade," where the acoustic activity increased dramatically, providing a clear and actionable warning period before the final break.

### 4. Discussion

### 4.1. Interpretation of Findings

The results unequivocally demonstrate the viability of piezoelectric sensors for event-based SHM. The key takeaway is the profound influence of the structural material on the sensor output. The development of the web-based DAQ system was a significant success, proving that sophisticated data collection and control can be achieved with low-cost, accessible technology. The success of the break test is the cornerstone of this research. It proves that a simple array of sensors can provide a clear, unambiguous, and sufficiently early warning of impending structural failure. The pre-failure cascade is not noise; it is the data-driven evidence of the bridge breaking in slow motion.

### 4.2. Sources of Error and Uncertainty

- Electromagnetic Interference (EMI): The unshielded wiring of the DAQ system is susceptible to EMI, contributing to the baseline noise of ~5-10 mV.
- Sensor Coupling: The consistency of the adhesive layer can affect the efficiency of mechanical-to-electrical energy transfer.
- ADC Resolution: The Arduino's 10-bit ADC has a resolution of ~4.88 mV.
- Manual Loading: Manual application of loads lacks perfect repeatability.

### 4.3. Critical Review and Future Improvements

- Controlled Excitation: Employing a mechanical shaker and a calibrated load frame would provide quantitative, repeatable data.
- Advanced DAQ: Utilizing a 24-bit DAQ with a higher sampling rate and proper shielding would increase signal fidelity.
- Sensor Calibration: Calibrating each sensor to correlate voltage (mV) with force (N) or strain (µ ) would transform the system from a qualitative detector to a quantitative
ϵ
measurement device.

### 5. Advanced Applications and Future Work

### 5.1. Towards a "Digital Twin"

A digital twin is a high-fidelity virtual model of a physical asset, updated in real-time by sensor data. The data from our instrumented bridges could be used to create a "live" Finite Element Analysis (FEA) model. The real-world sensor data would continuously update the boundary conditions of the virtual model, allowing it to predict stress concentrations and failure points with incredible accuracy.

### 5.2. AI and Machine Learning for Prognostic Health Management (PHM)

The voltage-time series data is a perfect candidate for analysis by Machine Learning (ML) algorithms. A neural network could be trained on the data from the break test to recognize the subtle acoustic signatures of different failure modes. This would evolve the SHM system from a warning system to a prognostic system, capable of not only predicting that a failure will occur, but how and when.

### 5.3. Energy Harvesting and Self-Sustaining Sensor Networks

The piezoelectric effect can be used to harvest ambient vibrational energy from the structure itself. This opens the door to creating completely self-powered, wireless sensor networks that could operate for decades without maintenance, a game-changer for monitoring remote infrastructure.

### 6. Conclusion

This investigation successfully validated the use of commercial piezoelectric transducers as a simple, yet remarkably powerful, tool for Structural Health Monitoring. Through a comparative study of traditional wood and modern 3D-printed structures, this paper has demonstrated that sensor response is intrinsically linked to the material properties of the host structure. The development of an integrated, web-based platform for test control and data visualization proved to be a highly effective method for streamlining the experimental process. The critical success of this project was the unambiguous detection of a clear pre-failure acoustic cascade during a destructive test. This provides definitive evidence of the system's potential as an early-warning tool for catastrophic failure. While acknowledging the limitations of the experimental setup, this research establishes a robust foundation for future work in creating quantitative, intelligent, and even self-powered SHM systems. The concepts explored herein, from a custom DAQ interface to AI integration, represent the future of engineering—a future where our infrastructure is not just built, but is born with a nervous system, capable of telling us when and where it hurts.

### 7. Appendix

Appendix A: Data Summary Tables

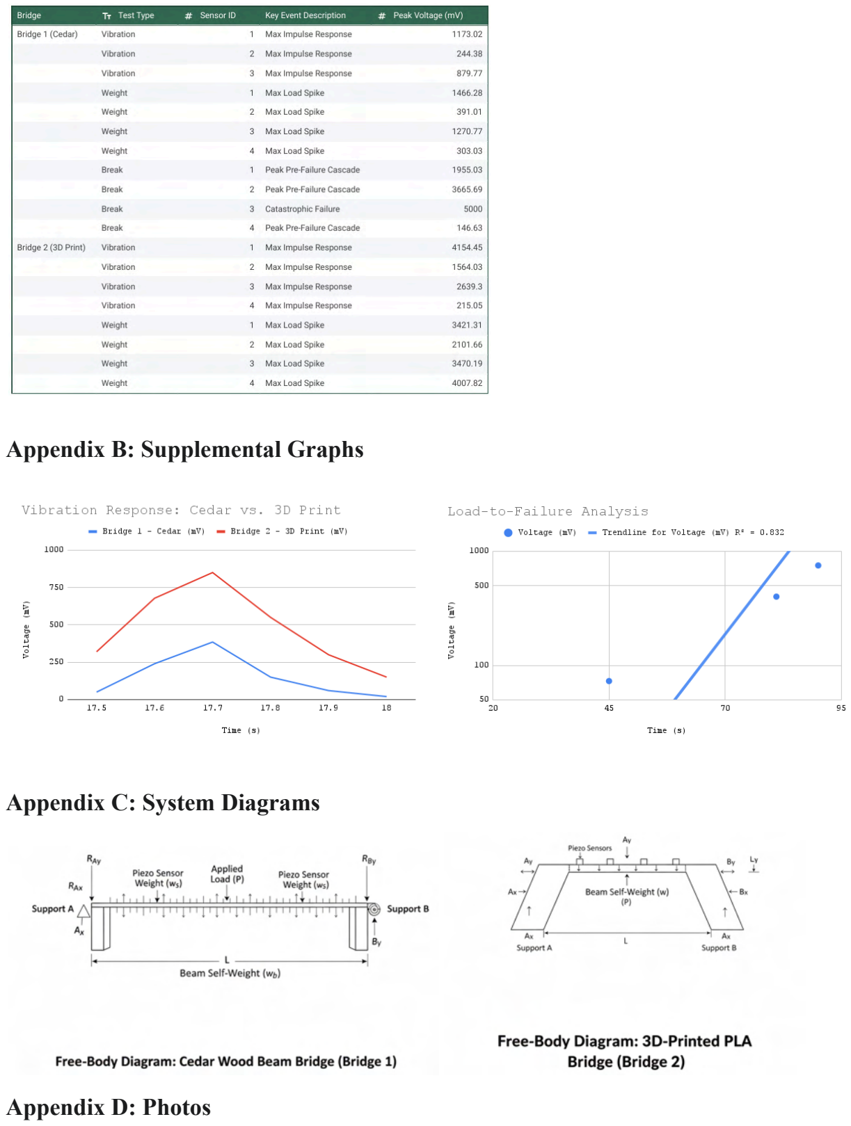
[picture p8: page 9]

Appendix B: Supplemental Graphs

Appendix C: System Diagrams

Appendix D: Photos

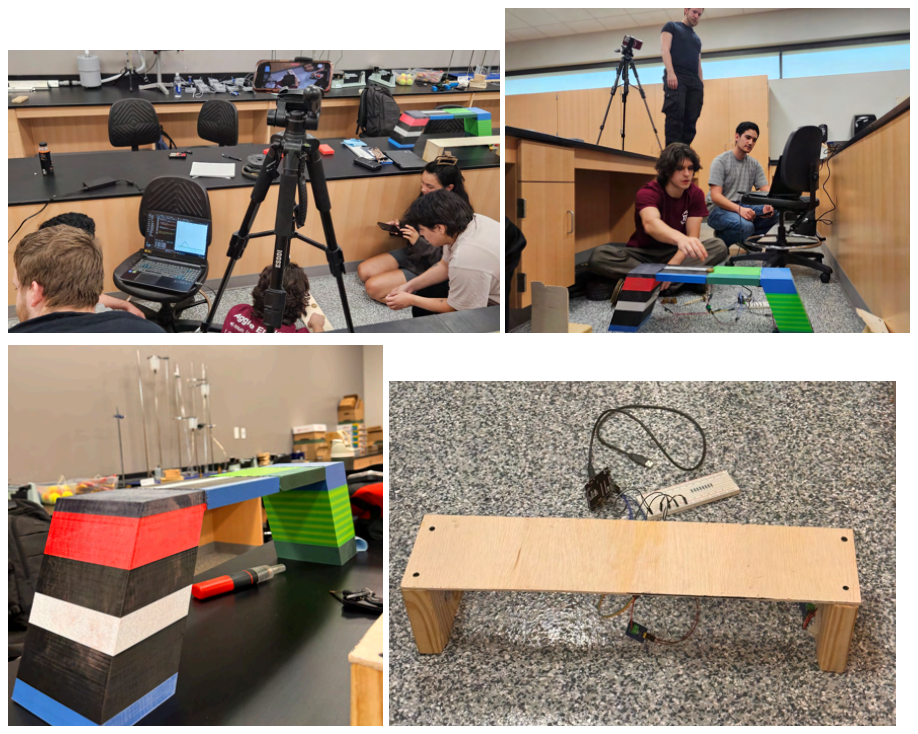
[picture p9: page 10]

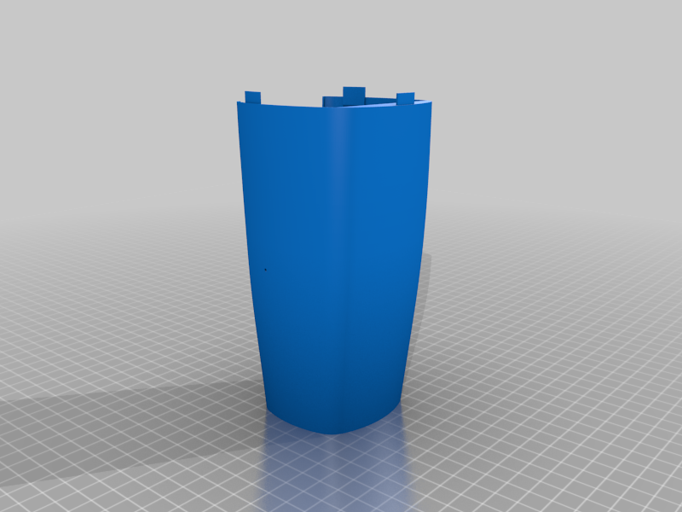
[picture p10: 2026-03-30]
images/36ea143ecf6969a36abb5eb5f7ab3737.png

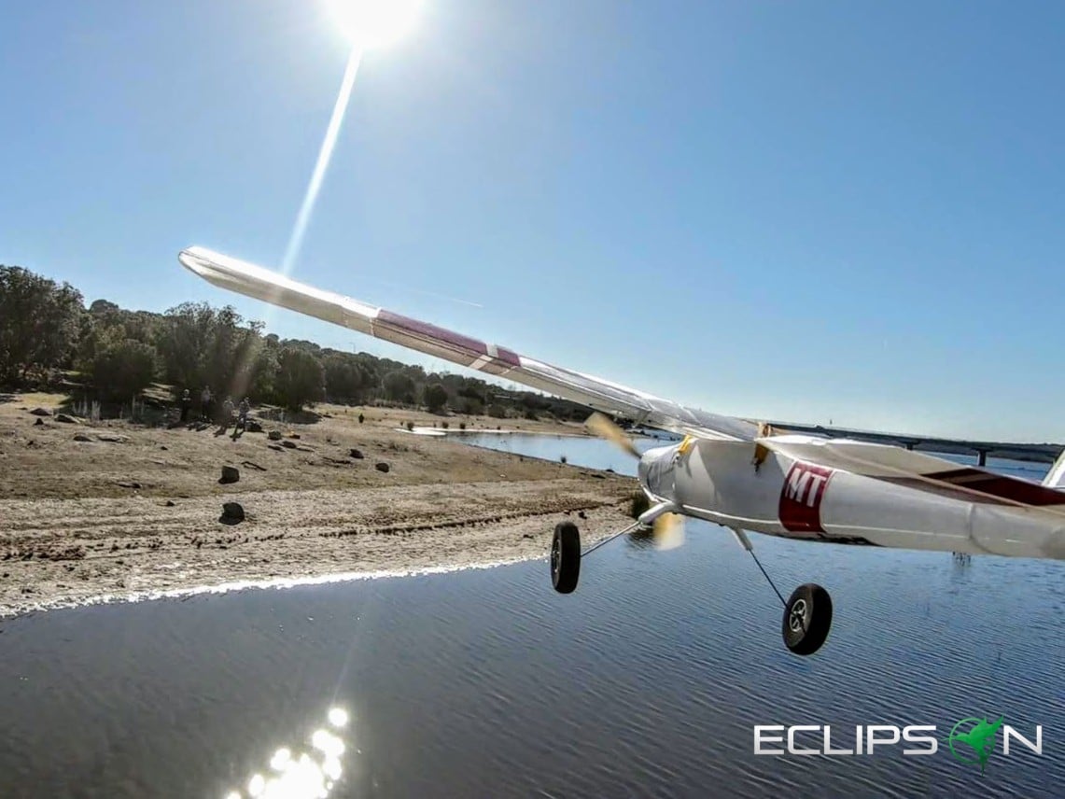
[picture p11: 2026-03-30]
images/IMG-20190109-WA0002_2.jpg

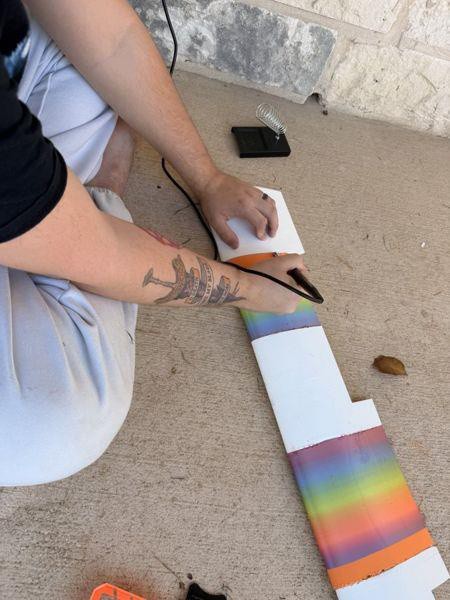
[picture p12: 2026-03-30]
uav_photo_3.jpg

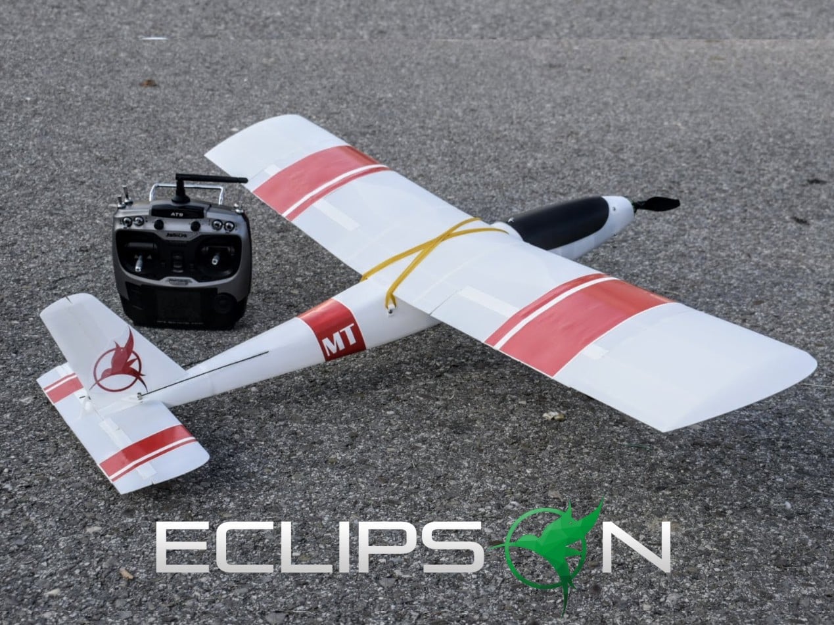
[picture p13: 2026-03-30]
images/_DSC0102.jpg

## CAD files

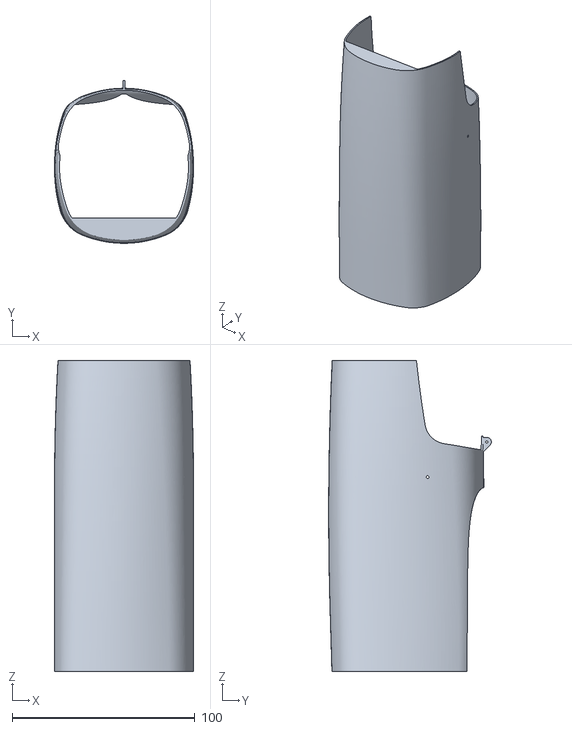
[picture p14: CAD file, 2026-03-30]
files/Fus2_FV.stl
76.0 x 88.9 x 170.0

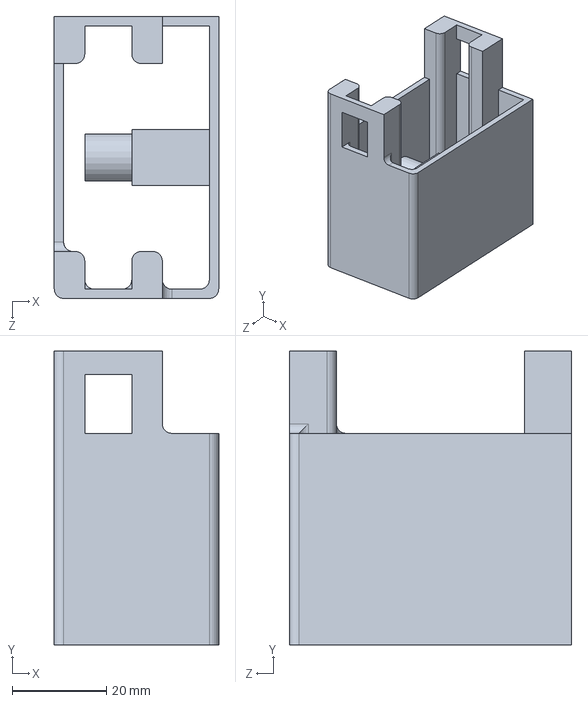
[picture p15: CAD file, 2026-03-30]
JNmotor box.SLDPRT
35.0 x 62.5 x 60.0 mm

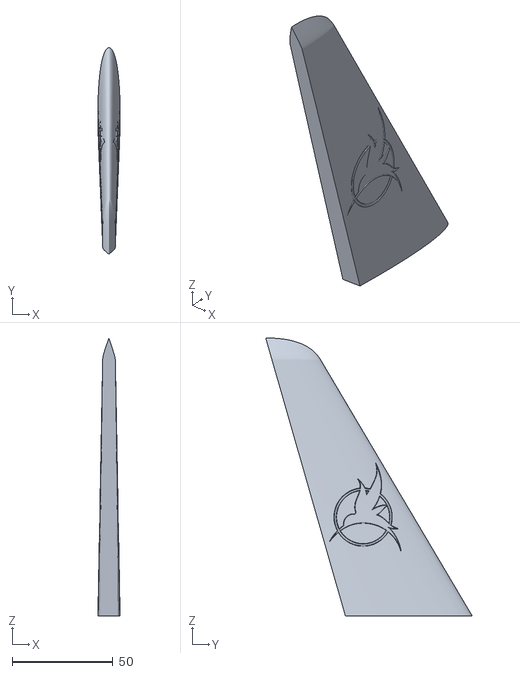
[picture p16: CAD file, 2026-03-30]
files/VTP_FV.stl
11.0 x 102.4 x 137.8

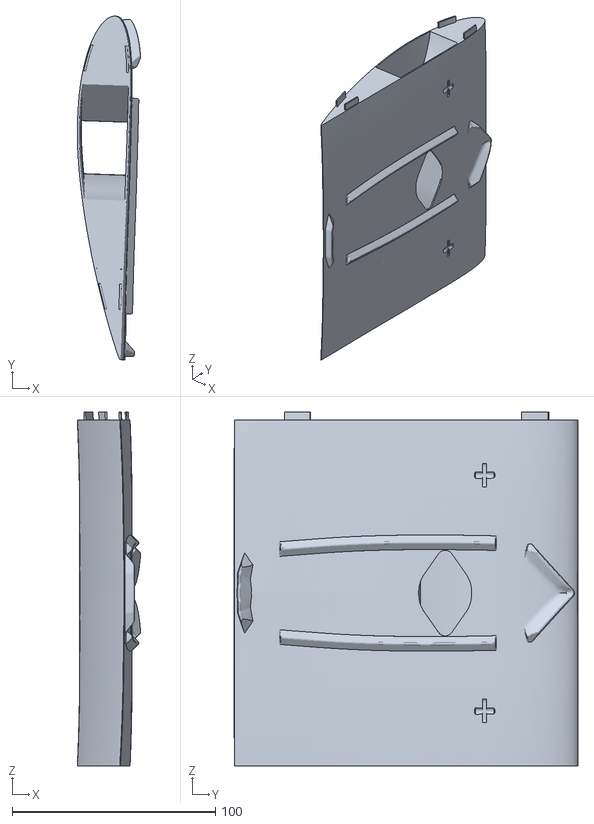
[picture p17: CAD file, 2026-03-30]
files/Wing_C.stl
31.2 x 168.9 x 174.0

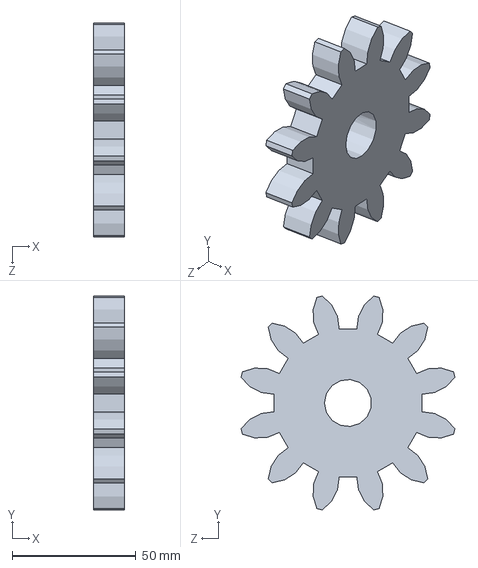
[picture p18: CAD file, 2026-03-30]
JNspur gear_am.SLDPRT
12.7 x 86.4 x 86.4 mm

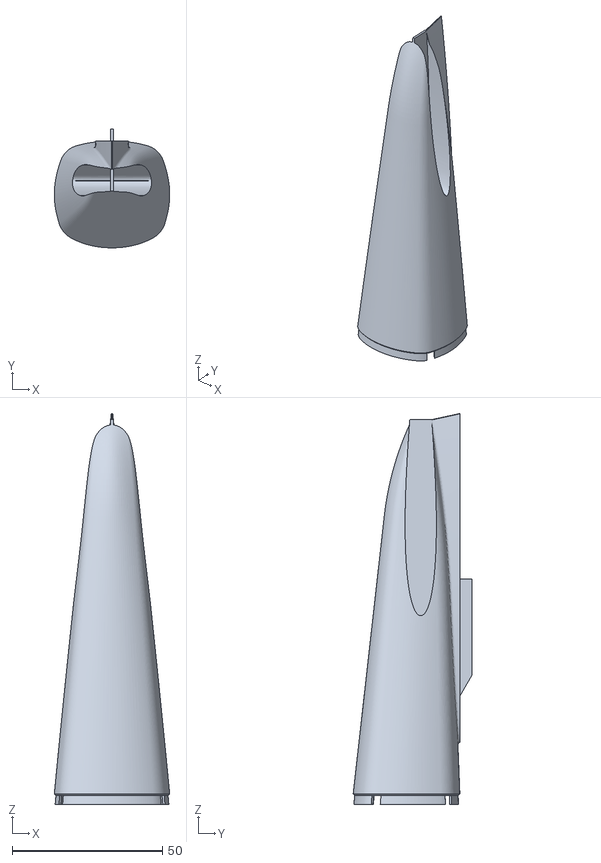
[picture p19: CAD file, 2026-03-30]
files/Fus5.stl
38.4 x 39.5 x 130.0

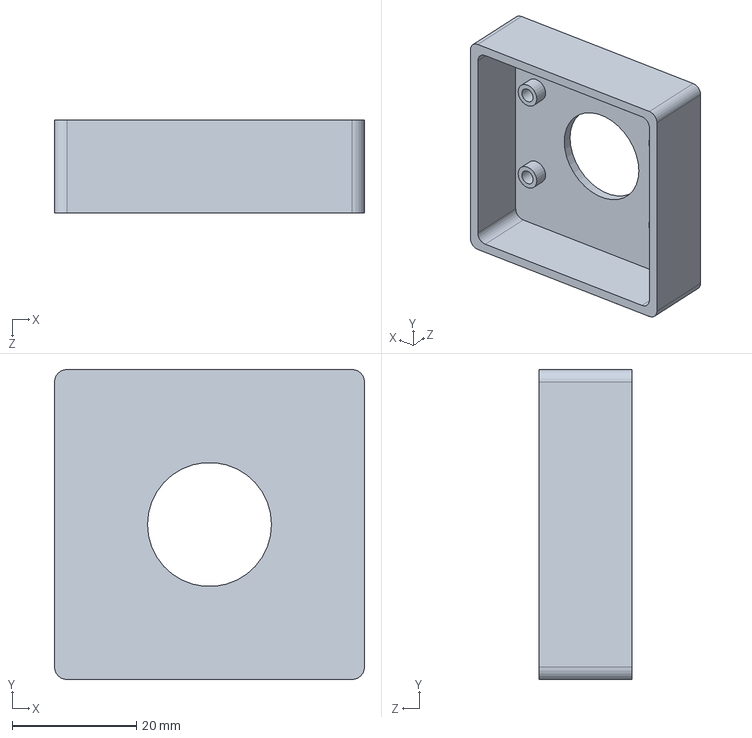
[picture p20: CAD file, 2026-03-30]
JNspectrometer box.SLDPRT
50.0 x 50.0 x 15.0 mm

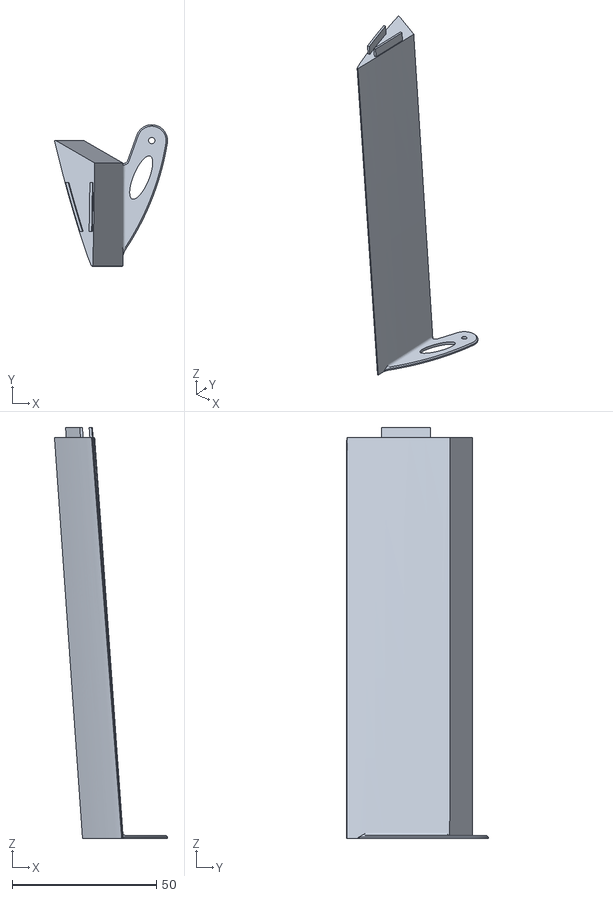
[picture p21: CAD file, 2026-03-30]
files/Aileron1R.stl
39.2 x 49.1 x 142.5

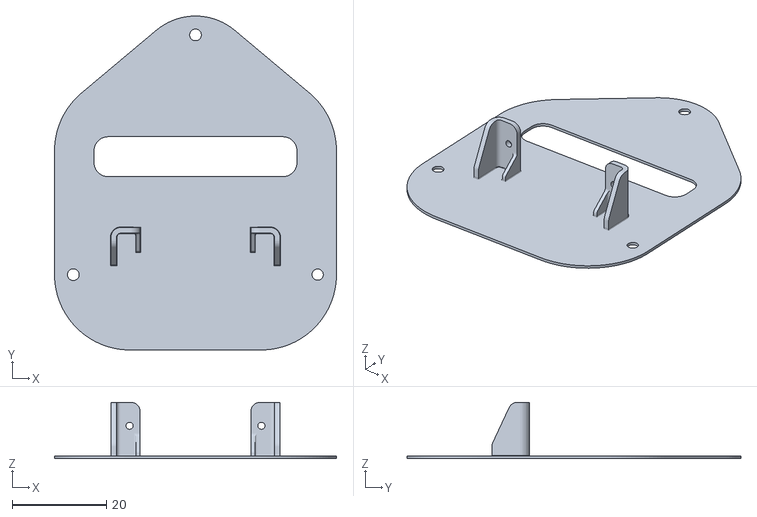
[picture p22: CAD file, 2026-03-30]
files/Servo_holder_Wing.stl
59.9 x 70.9 x 12.0

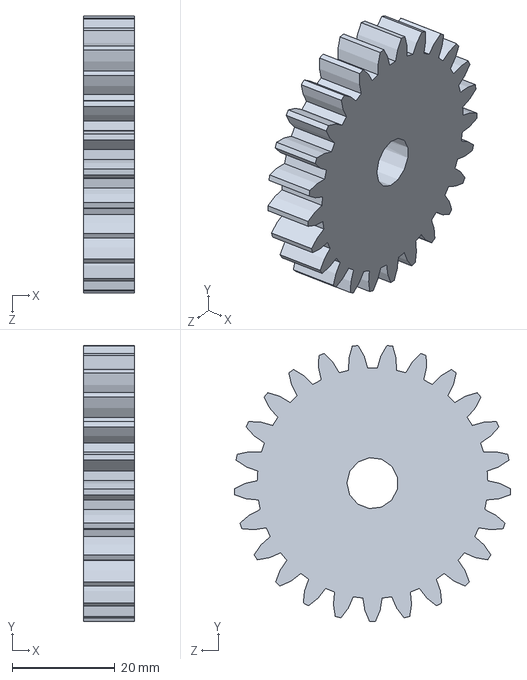
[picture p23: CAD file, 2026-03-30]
JNspur gear_am2.SLDPRT
10.0 x 53.8 x 54.0 mm

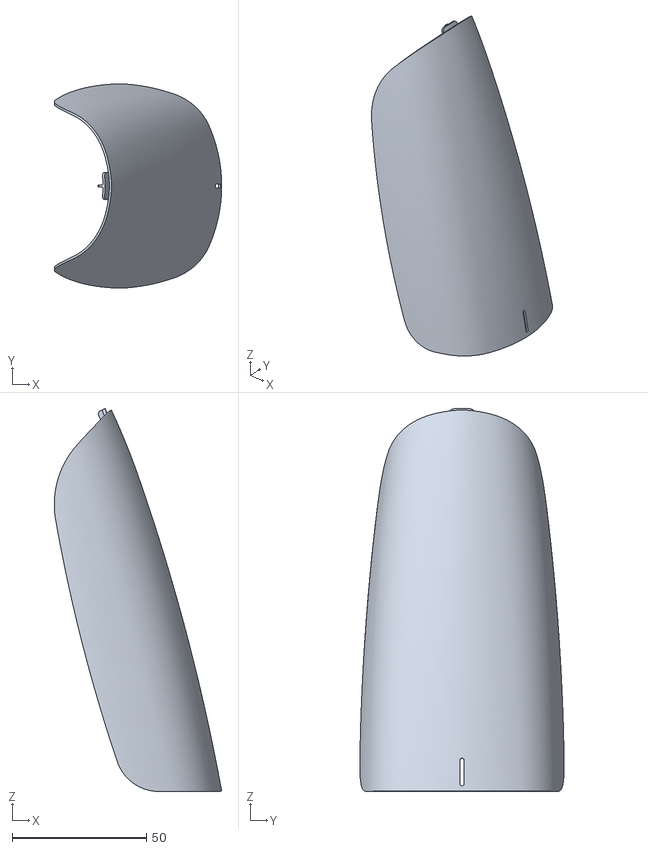
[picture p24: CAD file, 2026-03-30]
files/Canopy.stl
62.4 x 76.2 x 142.8

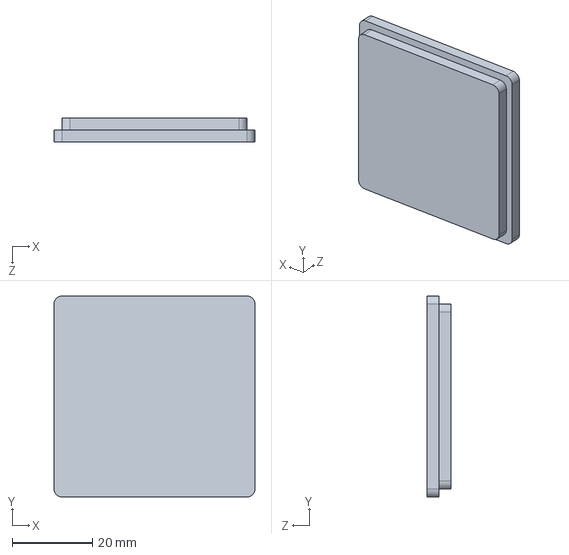
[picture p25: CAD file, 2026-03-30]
JNspectrometer box lid.SLDPRT
50.0 x 50.0 x 6.00 mm

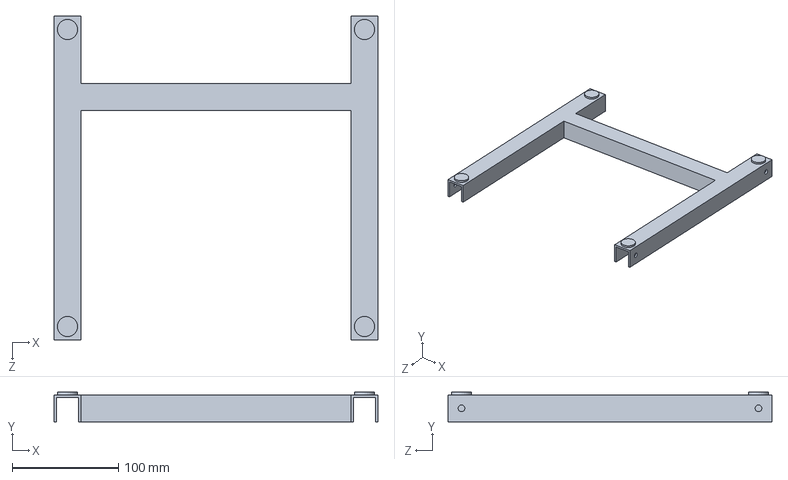
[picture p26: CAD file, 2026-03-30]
DIRT Chassis Frame Draft.SLDPRT
304.8 x 27.9 x 304.8 mm

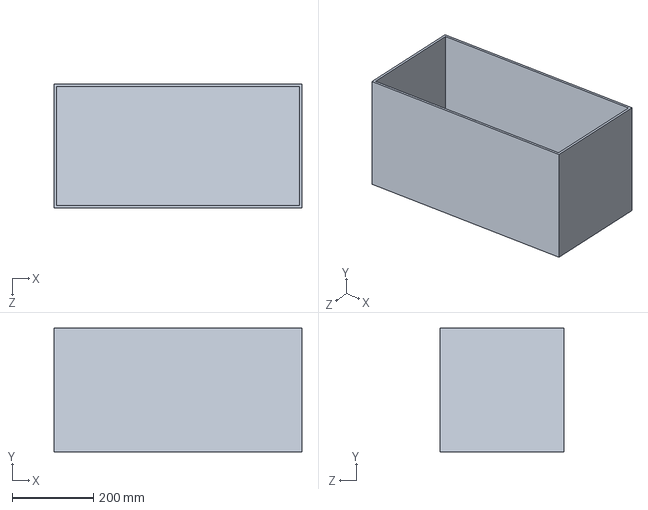
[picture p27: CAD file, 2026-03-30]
DIRT Chassis (Box).SLDPRT
609.6 x 304.8 x 304.8 mm

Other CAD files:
JNspectrometer elevator.SLDASM
MainAssem.obj
files/Aileron1L.stl
files/Fus3_FV.stl
Auger_Bit.SLDPRT
JNcorner bracket.SLDPRT
JNstop bracket.SLDPRT
files/Aileron2L.stl
files/Aileron2R.stl
files/Elev1L.stl
files/Elev2R.stl
files/Elev3R.stl
files/Fitting_rubber.stl
files/Fus1.stl
files/Fus4.stl
files/Guide.stl
files/HTP1L.stl
files/HTP1R.stl
files/Motor_holder.stl
files/Rudder.stl
files/Servo_holder_fus.stl
files/Wing1L.stl
files/Wing1R.stl
files/Wing2L.stl
files/Wing2R.stl
files/Wing3L.stl
files/Wing3R.stl

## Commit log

2026-03-30 Major portfolio enhancements: improved hero visuals, social icons, favicon, contact form, testimonials, blog section, case studies, and updated navigation
2026-03-30 Add reel, results strip, expandable case studies, growth timeline, animations, badges, and book-a-chat CTA
2026-03-30 Polish main portfolio UX: proof-first cards, inline case details, mobile quick-nav
2026-03-30 Add DIRT Rover CAD files and links to portfolio
    [Auger_Bit.SLDPRT, DIRT Chassis (Box).SLDPRT, DIRT Chassis Frame Draft.SLDPRT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]
2026-03-30 Switch rover viewer to Babylon OBJ renderer
2026-03-30 Tune procedural rover to CAD-inspired proportions
2026-03-30 Add interactive 3D plane viewer modal for fixed-wing UAV
2026-03-30 all new things
    [Aileron1L.stl, Aileron1R.stl, Aileron2L.stl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]
2026-03-30 Implement Three.js STL loader for real CAD plane model
2026-03-30 Fix STL assembly - preserve CAD coordinate system
2026-03-30 Orient CAD assembly as airplane with proper coordinate transform
2026-03-30 Smart part positioning based on names to assemble plane
2026-03-30 Fix part assembly - preserve CAD coordinates without centering
2026-03-30 Upgrade poker gate with scoring, stakes, timer, modes, sound, and win banner
2026-04-01 Add all features: recruitment mode, project filtering, skills matrix, timeline, collaboration panel, and Zanzibar game
2026-04-01 Update project stats and portfolio card title to match current A&M branding
2026-04-01 Fix recruitment mode toggle and enhance skills section with animations, filtering, and project attribution
